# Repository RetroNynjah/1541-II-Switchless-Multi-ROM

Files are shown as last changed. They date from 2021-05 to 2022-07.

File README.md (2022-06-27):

# Retroninja 1541-II Switchless Multi-ROM
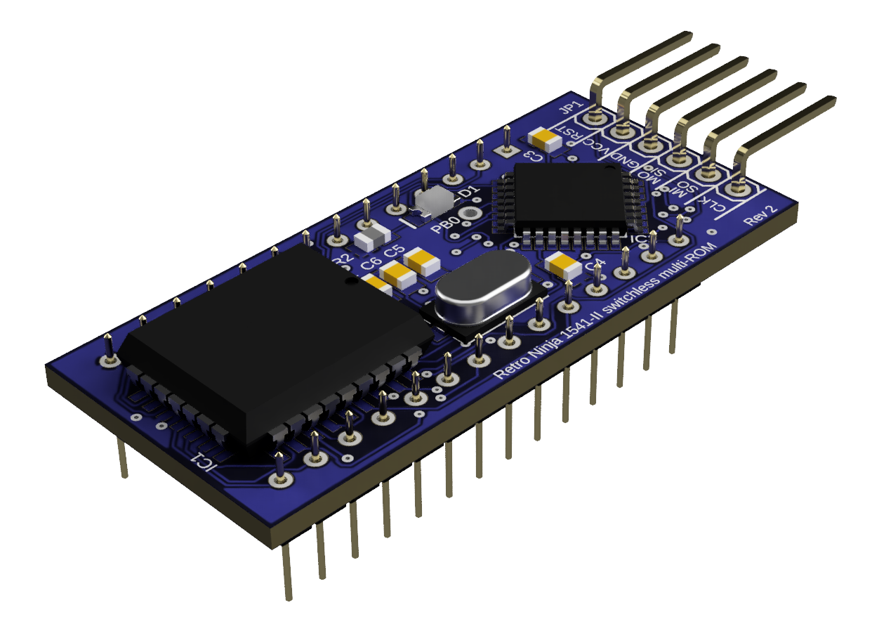
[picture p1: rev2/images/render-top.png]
Render top
<br/>
A microcontroller based switchless ROM switcher for the Commodore 1541-II disk drive.
Switch between stock CBM DOS, JiffyDOS and other ROMs by issuing commands from Basic.
No computer modifications or drive enclosure modifications needed. Completely reversible drive modification.

Read the user's guide for more information.

# A new revision of this board has been released under the more generic name [Switchless Multi-ROM for 27128 & 27256](https://github.com/RetroNynjah/Switchless-Multi-ROM-for-27128-27256)

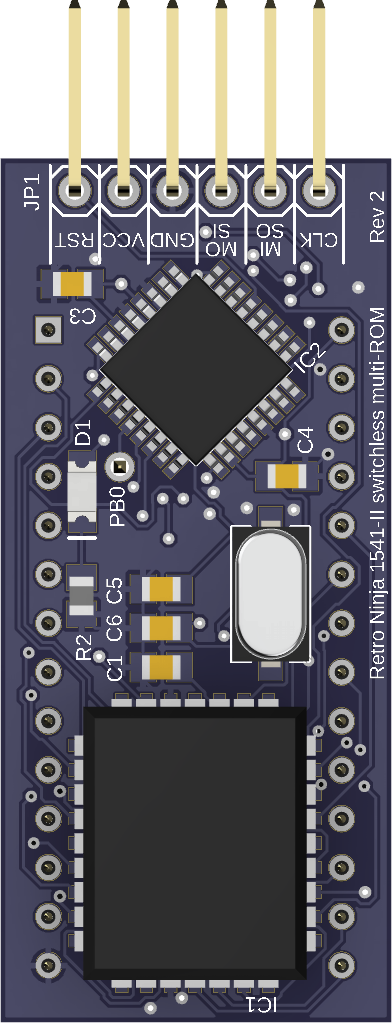
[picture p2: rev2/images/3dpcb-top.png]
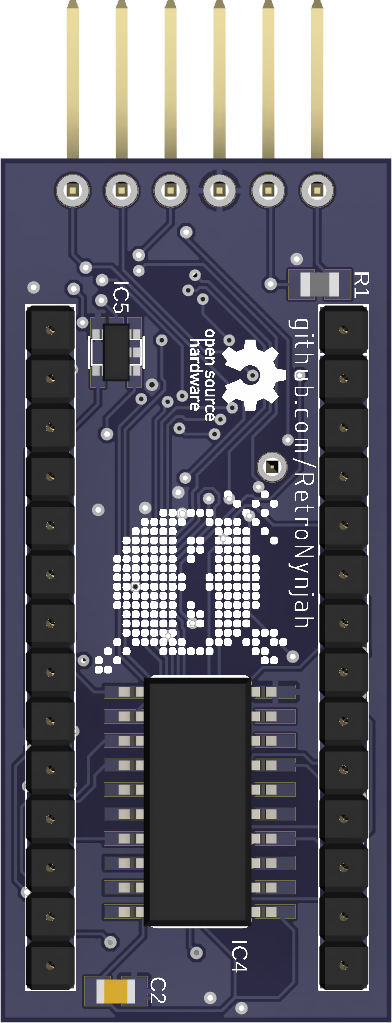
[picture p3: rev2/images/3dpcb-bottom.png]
Render bottom
  <br/>

## BOM
 |Component|Pcs |Name|Comment|
 |:--------|---:|:---|:------|
 | SST39SF010A | 1 | IC1 | Flash. SST39SF020/040 should work too. PLCC-32 |
 | ATMEGA328P-AU | 1 | IC2 | Or compatible ATmega8/48/88/168/328 variants. TQFP-32 |
 | 74AHCT273NSR | 1 | IC4 | Flip-Flop SO-20 (5.3mm width) |
 | 74AHCT1G04 | 1 | IC5 | Inverter single gate SOT-23 |
 | 100nF ceramic capacitor | 4 | C1, C2, C3, C4 | 0805 |
 | 30pF ceramic capacitor | 2 | C5, C6 | 0805 - 22pF works too |
 | 10k resistor | 1 | R1 | 0805 |
 | 560R resistor | 1 | R2 | 0805 - LED current limiting resistor|
 | LED | 1 | D1 | 1206 |
 | ECS-160-20-3X-TR | 1 | XTAL1 | Crystal 16MHz |
 | 14 pin header | 2 | "IC3" | Male machined pin headers or flat headers. 2.54mm pitch. To fit DIL-28 socket. |
 | 6 pin header right-angled | 1 | JP1 | Optional 2.54mm pitch. For ISP programmer. |

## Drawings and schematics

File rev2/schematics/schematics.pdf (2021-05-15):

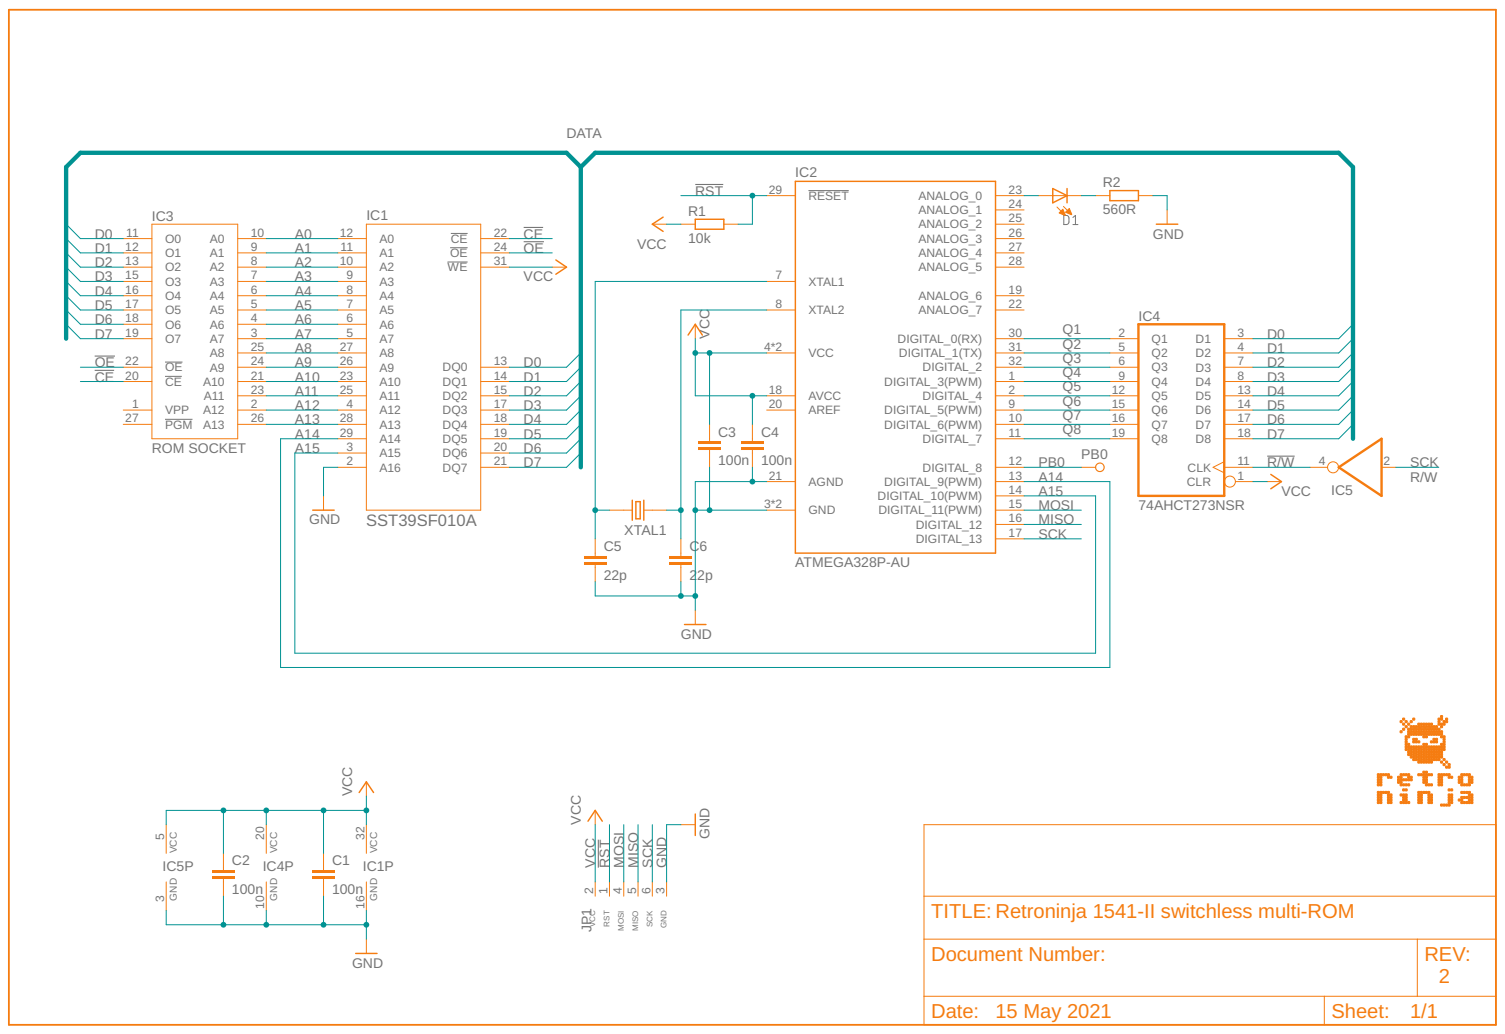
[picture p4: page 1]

Retroninja 1541-II switchless multi-ROM

SCK RST VCC MOSI GND

Document Number: | REV: 2

Date: 15 May 2021 | Sheet: 1/1

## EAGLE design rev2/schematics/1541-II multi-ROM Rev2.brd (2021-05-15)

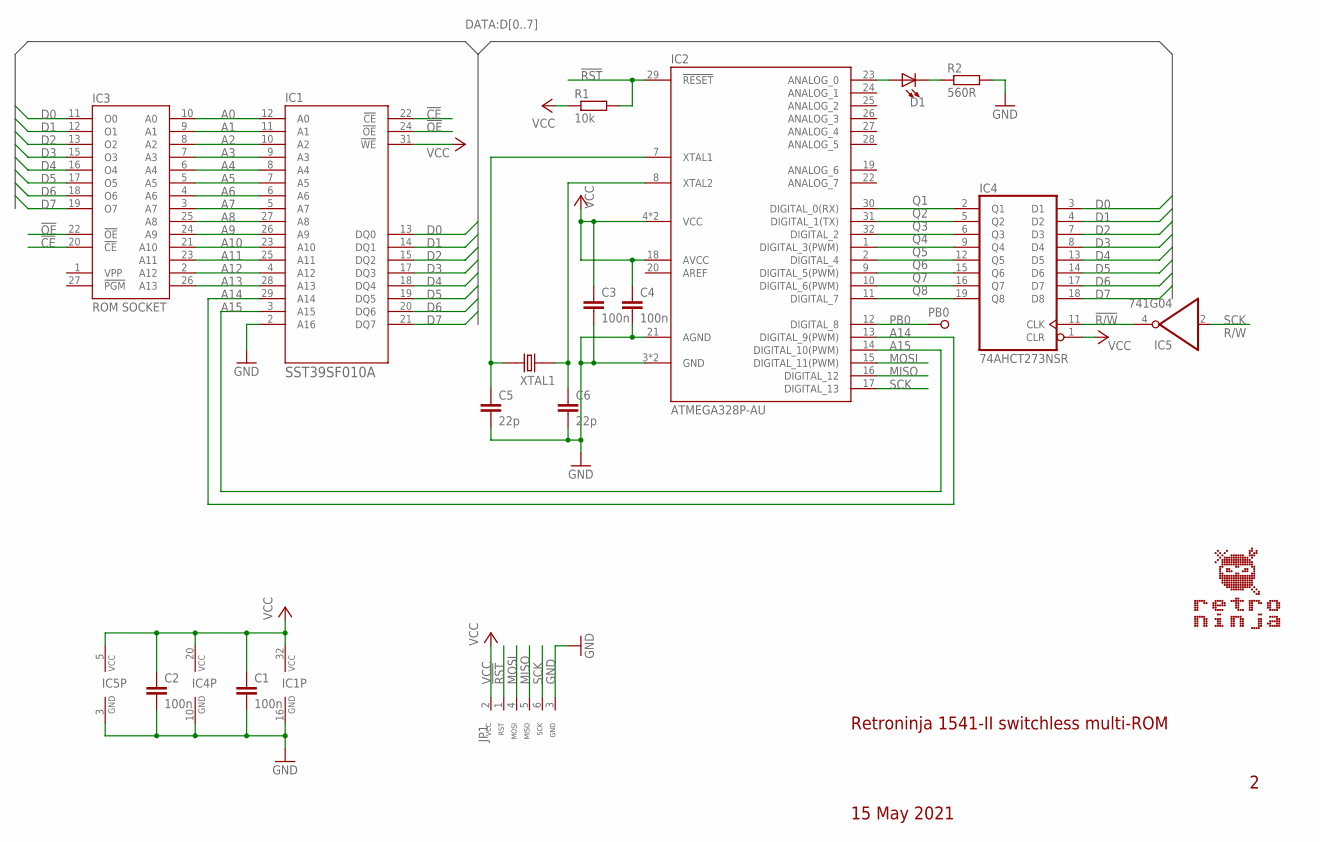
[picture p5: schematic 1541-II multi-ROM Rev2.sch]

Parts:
C1, C2, C3, C4: 100n; C0805
C5, C6: 22p; C0805
D1: LED_1206; LED1206
IC1: SST39SF010A; PLCC32_SHORT
IC2: ATMEGA328P-AU; TQFP32
IC3: ROM SOCKET; DIL28-6_DOWNPINS
IC4: 74AHCT273NSR; SO20
IC5: 741G04; SOT23-5
JP1: ICSP_CONNECTOR_TL866_RIGHT2; HEADER_1X6_RIGHT
PB0: TEST_POINT_TH
R1: 10k; R0805
R2: 560R; R0805
XTAL1: CRYSTAL; CRYSTAL_SMD-2_7X4X2.3

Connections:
!CE: IC1.22 (!CE), IC3.20 (!CE)
!OE: IC1.24 (!OE), IC3.22 (!OE)
!R/W: IC4.11 (CLK), IC5.4 (O)
!RST: IC2.29 (!RESET), JP1.1 (RST), R1.2
A0: IC1.12 (A0), IC3.10 (A0)
A1: IC1.11 (A1), IC3.9 (A1)
A2: IC1.10 (A2), IC3.8 (A2)
A3: IC1.9 (A3), IC3.7 (A3)
A4: IC1.8 (A4), IC3.6 (A4)
A5: IC1.7 (A5), IC3.5 (A5)
A6: IC1.6 (A6), IC3.4 (A6)
A7: IC1.5 (A7), IC3.3 (A7)
A8: IC1.27 (A8), IC3.25 (A8)
A9: IC1.26 (A9), IC3.24 (A9)
A10: IC1.23 (A10), IC3.21 (A10)
A11: IC1.25 (A11), IC3.23 (A11)
A12: IC1.4 (A12), IC3.2 (A12)
A13: IC1.28 (A13), IC3.26 (A13)
A14: IC1.29 (A14), IC2.13 (DIGITAL_9(PWM))
A15: IC1.3 (A15), IC2.14 (DIGITAL_10(PWM))
D0: IC1.13 (DQ0), IC3.11 (O0), IC4.3 (D1)
D1: IC1.14 (DQ1), IC3.12 (O1), IC4.4 (D2)
D2: IC1.15 (DQ2), IC3.13 (O2), IC4.7 (D3)
D3: IC1.17 (DQ3), IC3.15 (O3), IC4.8 (D4)
D4: IC1.18 (DQ4), IC3.16 (O4), IC4.13 (D5)
D5: IC1.19 (DQ5), IC3.17 (O5), IC4.14 (D6)
D6: IC1.20 (DQ6), IC3.18 (O6), IC4.17 (D7)
D7: IC1.21 (DQ7), IC3.19 (O7), IC4.18 (D8)
GND: C1.2, C2.2, C3.2, C4.2, C5.2, C6.2, IC1.2 (A16), IC1.16 (GND), IC2.3 (GND), IC2.5 (GND), IC2.21 (AGND), IC3.14 (GND), IC4.10 (GND), IC5.3 (GND), JP1.3 (GND), R2.2
MISO: IC2.16 (DIGITAL_12), JP1.5 (MISO)
MOSI: IC2.15 (DIGITAL_11(PWM)), JP1.4 (MOSI)
unnamed: C6.1, IC2.8 (XTAL2), XTAL1.1
unnamed: C5.1, IC2.7 (XTAL1), XTAL1.2
unnamed: D1.A, IC2.23 (ANALOG_0)
unnamed: D1.C, R2.1
PB0: IC2.12 (DIGITAL_8), PB0.P$1
Q1: IC2.30 (DIGITAL_0(RX)), IC4.2 (Q1)
Q2: IC2.31 (DIGITAL_1(TX)), IC4.5 (Q2)
Q3: IC2.32 (DIGITAL_2), IC4.6 (Q3)
Q4: IC2.1 (DIGITAL_3(PWM)), IC4.9 (Q4)
Q5: IC2.2 (DIGITAL_4), IC4.12 (Q5)
Q6: IC2.9 (DIGITAL_5(PWM)), IC4.15 (Q6)
Q7: IC2.10 (DIGITAL_6(PWM)), IC4.16 (Q7)
Q8: IC2.11 (DIGITAL_7), IC4.19 (Q8)
SCK: IC2.17 (DIGITAL_13), IC5.2 (I), JP1.6 (SCK)
VCC: C1.1, C2.1, C3.1, C4.1, IC1.31 (!WE), IC1.32 (VCC), IC2.4 (VCC), IC2.6 (VCC), IC2.18 (AVCC), IC3.28 (VCC), IC4.1 (CLR), IC4.20 (VCC), IC5.5 (VCC), JP1.2 (VCC), R1.1

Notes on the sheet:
R/W
Retroninja 1541-II switchless multi-ROM
15 May 2021

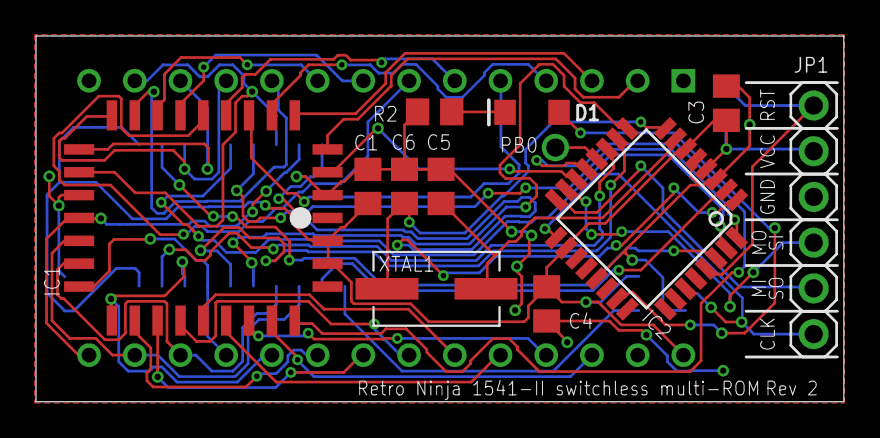
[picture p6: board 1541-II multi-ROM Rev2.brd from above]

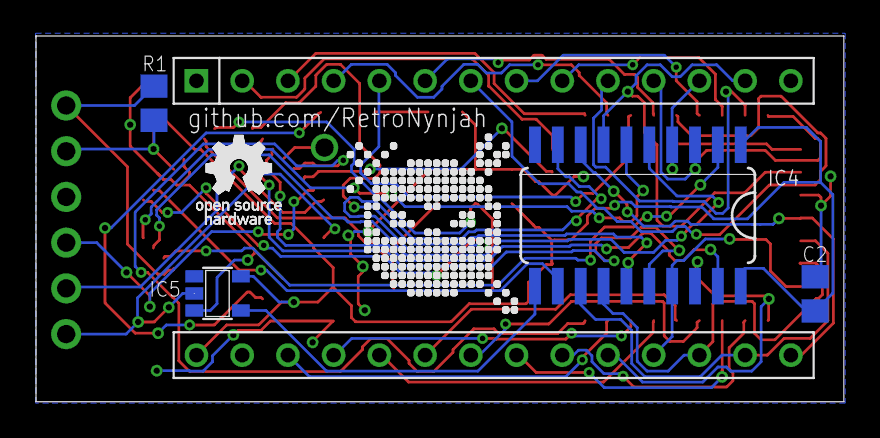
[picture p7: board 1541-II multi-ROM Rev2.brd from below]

Board: 2 copper layers, 44.9 x 20.3 mm, 19 parts (6 on the bottom side), 46 nets.

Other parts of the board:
U$1: RETRONINJA_NOTEXT_10MM
U$2: OSHW_5MM

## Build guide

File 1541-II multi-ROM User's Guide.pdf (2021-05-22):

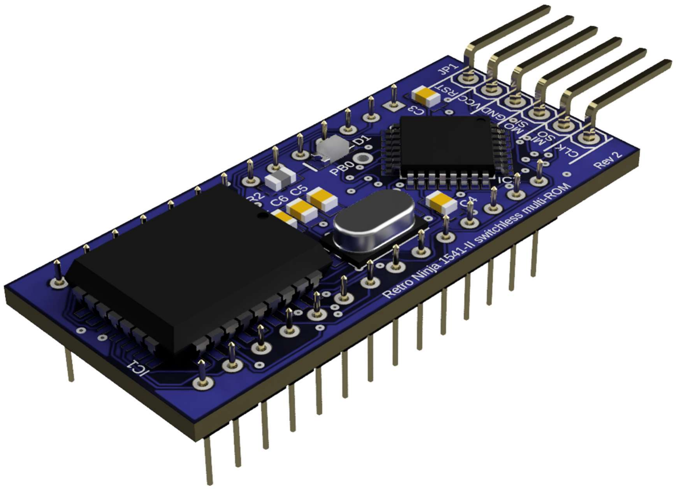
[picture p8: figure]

P a g e 1 | 6

# Switchless Multi-ROM for CBM 1541-II User’s Guide

This microcontroller-based switchless ROM-switcher for the 1541-II disk drive lets you switch drive ROM between stock CBM DOS and JiffyDOS or other DOS version using simple basic commands.

## Usage

The switcher is listening to the data bus for a predefined word and a number. The easiest way to send the word to the drive is to issue a load command to the drive from basic with the word as filename.
The default magic word is #@RNROM where # is the number of the ROM image you want to switch to.
LOAD “1@RNROM”,8 switches drive 8 to DOS image 1 and LOAD “2@RNROM”,8 switches to image 2 and so on. The default valid range of numbers is 1-4.
The drive will respond with a file not found error but the programmer will pick up the command, blink the multi-ROM LED to indicate which image was selected, switch the ROM by setting the high address pins accordingly and reset the drive using the newly selected ROM.
The selected ROM will be remembered and used at power-on.

Retroninja 1541-II switchless multi-ROM | User’s Guide version 1.1

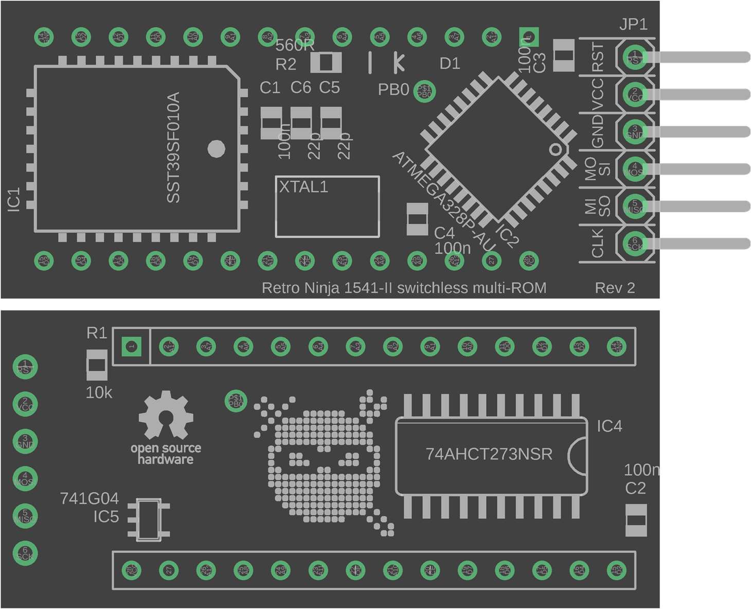
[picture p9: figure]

P a g e 2 | 6

## Theory of operation

At power on, the microcontroller in the ROM switcher reads address 0 from its internal EPROM to find out which ROM it should select, sets the address A14-A15 on the flash chip and resets the drive to make sure it’s booted with the correct image. This can be noticed when the drive is powered on and the drive initializes and stops spinning and then spins up again briefly during the switch reset. It then starts listening for a switch command.
Even at a clock speed of 16 MHz, reading and analyzing a 1MHz data bus can be a challenge so the data on the 1541-II data bus is buffered in the switcher by a 74AHCT273 flip-flop that is clocked by the Write signal on the 6502 MPU in the 1541-II. By clocking the data with the R/W signal we filter out irrelevant bus traffic and the flip-flop holds the data until the next write cycle. This gives the microcontroller enough time to read the data from the flip-flop.
The microcontroller listens for a predefined sequence of bytes in reverse order (MORNR@) and once the sequence is found, it treats the following numeric character as the target ROM image number. The reverse order of the characters on the bus is why the image number must be specified at the beginning of the command.
The microcontroller sets address pins A14-A15 on the flash chip according to image selection and it stores the ROM number at address 0 of its internal EPROM for use at next power-on. It then resets the drive by toggling the IEC reset line.

## Building the circuit

The switcher is small and a bit difficult to solder but it can be hand soldered. The reason for the small size is space constraints in the 1541-II and some other drives.
The Flash chip is the trickiest part to solder and I recommended reflow soldering the top side using stencil and solder paste. Then solder the bottom side by hand and finally solder the pin headers.

P a g e 3 | 6

### Parts

The switcher is designed for the SST39SF010A flash chip but the bigger SST39SF020/SST39SF040 could be used too if no SST39SF010A is available. Remember to duplicate the flash contents to fill all of flash to prevent floating pins from switching to empty flash areas.
The microcontroller does not have to be an ATmega328P but it is much easier if you want to program it from the Arduino IDE as it will be seen as an Arduino UNO.
It could be possible to replace it with other compatible MCUs such as variations of ATmega8/48/88/168/328 if you find or create the right Arduino board definitions for compiling the firmware. The chip needs to be pin-compatible with the ATmega328P TQFP-32 and capable of running at 16MHz so the V and PB variations will not work. I have used the ATmega88A.
The flip-flop needs to be a 74AHCT273. LS/HCT/AHC or any other variant will most likely not work. The 74AHCT1G04 single gate inverter is needed for inverting the active low write signal from the 6502 to the active high clock input of the flip-flop.
The crystal should be a 16MHz crystal but 20 MHz might work too if you recompile the sketch and burn the fuses accordingly. Not tested.
The LED on the board is optional but flashes a number of times indicating the number of the selected ROM when switching. It is only there for debugging reasons.
The pin headers that goes into the ROM socket should have round machined pins or be of that long flat type that is used for the pass-through pin headers on Arduino shields.
Square pin headers destroy the ROM socket in the drive.

### Programming the microcontroller

The recommended microcontroller for this board is an ATmega328P. The code for the controller was created using the Arduino environment and the device can be programmed in circuit from a sketch in the Arduino IDE using an ISP programmer. The board type can be set to Arduino UNO.
It can be programmed using AVRDUDE and the pre-compiled HEX file or using the popular TL866II programmer. The pin-out of the programming pins on the PCB matches the pin-out of the TL866II ICSP connector so a straight 6-pin cable can be used.
If you use an ATmega328P, the fuse settings should be the same as for an Arduino UNO. lfuse=0xFF, hfuse=0xDE, efuse=0xFD
How to use an Arduino as ISP or how to use an ISP programmer such as a USBASP will not covered by this document.

### Programming the flash chip

Due to space constraints, there are no on-board programming headers for the flash chip so the flash chip must be programmed in a flash/EPROM programmer before soldering it to the board or desoldered for reprogramming.
It could also be possible to make a programming adapter to put on top of the flash chip to program it while it’s still soldered to the board but this is not tested.
The ROM chip in the 1541-II is only 128 kbit (16 kilobyte) while the flash chip is 1 Mbit (128 kilobyte). It’s highly recommended to fill the entire flash chip with working DOS images to prevent bricking of the drive by selecting a non-existing image. The switcher will not work without a working ROM in the drive that can receive the serial data and put it on the data bus.
If you just use two ROM images, fill the flash with the same two images over and over for safety.

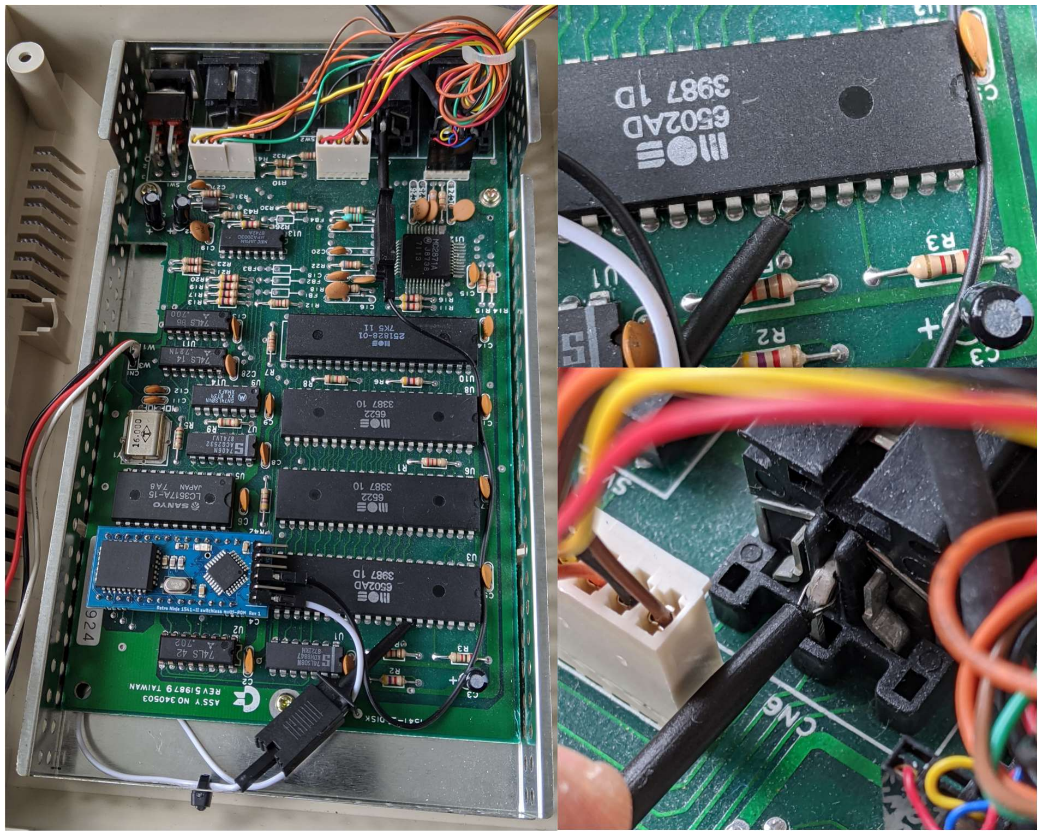
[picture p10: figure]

P a g e 4 | 6

## Installation

The circuit can be installed in the drive without soldering by using DuPont cables with test clips that attaches to the R/W pin on the 6502 MPU and to the reset pin on the back of any of the IEC connectors. However, it is recommended to solder the cables to the pins on the bottom of the drive PCB. That makes for a much more robust and transportable solution.
An even more stable solution is to solder the cables to the edge of the switcher PCB instead of using a pin header but that could make it harder to upgrade the firmware in the future.
The edge of the Multi-ROM PCB with the six ISP pins should face the notched end of the ROM socket (Pin 1).

The clock signal (CLK on the Multi-ROM) connects to the R/W pin (pin 34) on the 6502 MPU.
MOSI on the Multi-ROM connects to IEC reset. That’s the center pin on the back of the IEC connectors. The Multi-ROM works without a connection to IEC reset but a manual drive reset would then be needed after switching ROM.
The sketch and a pre-compiled firmware for the Multi-ROM can be found at https://github.com/RetroNynjah/1541-II-Switchless-Multi-ROM

P a g e 5 | 6

## Troubleshooting

If the device becomes bricked due to an incorrect DOS image, program the ATmega with a sketch that sets byte 0 to 0x00 or 0xFF in the internal EPROM. Then upload the original Multi-ROM sketch again and you should be back on track.
Switching may not work if you are using a fast loader such as Action Replay in your computer. Try switching the ROM without the fast loader. Switching ROM using JiffyDOS in the C64 is working fine though.

## Possible other uses

The switcher could possibly be used for other 27128 ROM switching applications if you can find the right clock signal and strings to listen for.
The switcher works in other 1541-II compatible drives that are using 27128 ROM too. For example the Enhancer 2000.

## Change history

This is the change history for the user’s guide.
For changes to the schematics, PCB or firmware, please refer to the GitHub repository at https://github.com/RetroNynjah/1541-II-Switchless-Multi-ROM
Date | Version | Description
2021-05-15 | 1 | Initial version
2021-05-22 | 1.1 | Alternative ATmega MCUs

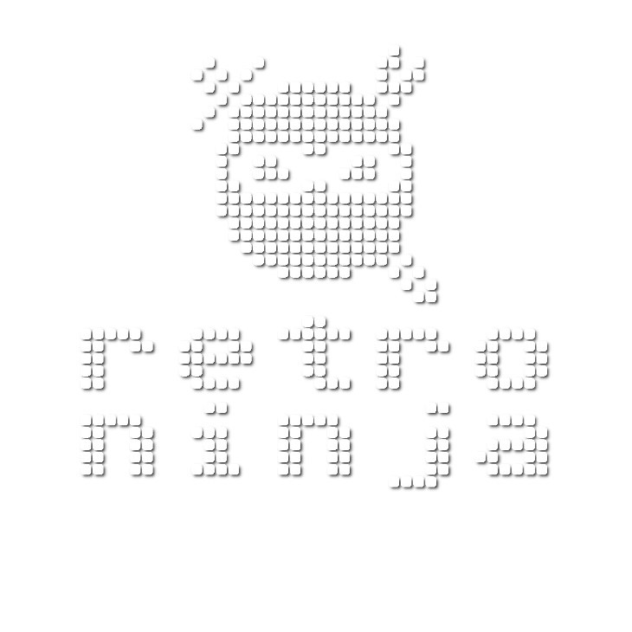
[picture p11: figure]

P a g e 6 | 6

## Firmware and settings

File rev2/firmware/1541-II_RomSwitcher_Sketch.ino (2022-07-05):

#include <EEPROM.h>

// searchString is the command that is used for switching ROM.
// It is passed by the 1541-II in reverse order so the variable should be reversed too.
// The command should be preceded by a ROM number between 1 and 4 when used.
// The below reversed searchString in hex ascii is MORNR@ which is specified like this on the C64: 1@RNROM, 2@RNROM and so on.
byte searchString[] = {0x4D,0x4F,0x52,0x4E,0x52,0x40};

int resetPin = 11;
int clockPin = 13;
int ledPin = A0;

int commandLength = sizeof(searchString);
int bytesCorrect = 0;
volatile bool state;


void pciSetup(byte pin)
{
    *digitalPinToPCMSK(pin) |= bit (digitalPinToPCMSKbit(pin));  // enable pin
    PCIFR  |= bit (digitalPinToPCICRbit(pin)); // clear any outstanding interrupt
    PCICR  |= bit (digitalPinToPCICRbit(pin)); // enable interrupt for the group
}



ISR (PCINT0_vect) // handle pin change interrupt for D8 to D13 here
{    
       // read state of pin 13
       state = PINB & B00100000;
}
 

void cleareeprom(){
  for (int i = 0 ; i < EEPROM.length() ; i++) {
    EEPROM.write(i, 0);
  }
}


void resetdrive(){
  
  pinMode(resetPin, OUTPUT); // reset pin
  digitalWrite(resetPin, LOW);
  delay(50);
  digitalWrite(resetPin, HIGH);
  delay(50);
  digitalWrite(resetPin, LOW);
  pinMode(resetPin, INPUT);

}


void switchrom(int romnumber){

  // switch eprompin A14 (D8)
  if (romnumber & B00001){
    digitalWrite(8, HIGH);
  }  
  else {
    digitalWrite(8, LOW);
  }

  // switch eprompin A15 (D9)
  if (romnumber & B00010){
    digitalWrite(9, HIGH);
  }  
  else {
    digitalWrite(9, LOW);
  }

  // switch eprompin A16 (D10)
  if (romnumber & B00100){
    digitalWrite(10, HIGH);
  }  
  else {
    digitalWrite(10, LOW);
  }

  // switch eprompin A17 (A1)
  if (romnumber & B01000){
    digitalWrite(A1, HIGH);
  }  
  else {
    digitalWrite(A1, LOW);
  }

  // switch eprompin A18 (A2)
  if (romnumber & B10000){
    digitalWrite(A2, HIGH);
  }  
  else {
    digitalWrite(A2, LOW);
  }

  int savedROM = EEPROM.read(0);
  if (savedROM != romnumber){
    EEPROM.write(0, romnumber);
  }

  for (int x = 0; x <= romnumber; x++){
    digitalWrite (ledPin, HIGH);
    delay(30);
    digitalWrite (ledPin, LOW);
    delay(250);
  }
  delay (200);

  resetdrive();

}



// function for debugging using onboard LED
void blinknumber(int num) {
  int hundreds = num / 100;
  int tens = num % 100 / 10;
  int singular = num % 10;
  
  for (int x = 1; x <= 10; x++){
    digitalWrite(ledPin, HIGH);
    delay(50);
    digitalWrite(ledPin, LOW);
    delay(50);
  }
  delay(2000);

  for (int x = 1; x <= hundreds; x++){
    digitalWrite(ledPin, HIGH);
    delay(50);
    digitalWrite(ledPin, LOW);
    delay(350);
  }
  delay(2000);

  for (int x = 1; x <= tens; x++){
    digitalWrite(ledPin, HIGH);
    delay(50);
    digitalWrite(ledPin, LOW);
    delay(350);
  }
  delay(2000);

  for (int x = 1; x <= singular; x++){
    digitalWrite(ledPin, HIGH);
    delay(50);
    digitalWrite(ledPin, LOW);
    delay(350);
  }
}



void setup() {

  // set data pins as inputs
  DDRD = B00000000;
  
  pinMode(8, OUTPUT); // eprom A14
  pinMode(9, OUTPUT); // eprom A15
  pinMode(10, OUTPUT); // eprom A16
  pinMode(A1, OUTPUT); // eprom A17
  pinMode(A2, OUTPUT); // eprom A18
  pinMode(resetPin, INPUT);
  pinMode(ledPin, OUTPUT);
  pinMode(clockPin, INPUT);
  
  // retrieve last used ROM from ATmega EEPROM and switch ROM using A14/A15
  int lastROM = EEPROM.read(0);
  if (lastROM > 4){
    cleareeprom();
    lastROM = 0;
  }
  switchrom(lastROM);
  
  // enable pin change interrupt on pin D13(PB5) connected to R/W on 6502
  pciSetup(clockPin);
}


void loop() {
  if (state == HIGH){
    byte byteCurr = PIND;
    state=LOW;
      
    if (bytesCorrect == commandLength){
      // we have our search string. This byte must be the ROM number
      // valid numbers are 1-4 (ASCII 49-52)
      if ((byteCurr >= 49)&&(byteCurr<=52)){
        // rom number within valid range. Switch rom
        switchrom(byteCurr - 49);
      }
      else{
        bytesCorrect=0;
      }
      //blinknumber(byteCurr);
    }

    // we don't have full search string yet. check if current byte is what we are looking for
    if (byteCurr == searchString[bytesCorrect]){
      // increase bytesCorrect to check for next character
      bytesCorrect++;
    }
    else {
      bytesCorrect = 0;
    }
  }
}

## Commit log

2021-05-15 Update README.md
    Adjusted BOM
2021-05-15 Update README.md
    Corrected SMD LED size
2022-07-05 Replaced 1541-II_RomSwitcher_Sketch.ino
    Wrong file uploaded
    [1541-II_RomSwitcher_Sketch.ino]
